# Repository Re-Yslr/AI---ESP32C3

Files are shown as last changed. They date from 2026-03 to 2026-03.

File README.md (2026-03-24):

# 机械AI仿生花 - Mechanical AI Bionic Flower

> 基于 xiaozhi-esp32 框架的毕业设计项目 | Graduation Design Project

## 项目简介

这是一个具有AI语音交互能力的机械仿生花项目。花朵可以根据AI对话状态自动开合，配合LED灯光效果，创造出富有生命力的交互体验。

**核心功能**：
- AI语音对话交互
- 花朵自动开合动画
- WS2812 RGB灯带氛围效果
- 3个物理按钮交互
- MCP协议智能设备控制

---

## 实物展示

### 功能演示

https://github.com/user-attachments/assets/功能演示.mp4

### 成品图片

| 框架成品 | 内部结构 |
|:---:|:---:|
| 框架成品图 | 内部成品 |

---

## 制作想法

### 设计理念

本项目试图探索"人机交互"的新形式——让AI不只是冰冷的屏幕对话，而是赋予它一个可以触摸、可以感知的物理实体。

**灵感来源**：
- 花朵的开合如同呼吸，具有自然的生命韵律
- AI"苏醒"时花朵绽放，"休眠"时花朵合拢
- 语音对话时花朵轻轻摇摆，仿佛在倾听和思考

### 工作流程

```
┌─────────────────────────────────────────────────────────┐
│                      状态流转                            │
├─────────────────────────────────────────────────────────┤
│                                                         │
│   [待命] ──唤醒词──> [聆听] ──识别完成──> [思考]        │
│     │                  │                  │             │
│   花朵合拢          花朵绽放            花朵摇摆         │
│   灯光常亮          灯光呼吸            灯光闪烁         │
│     │                  │                  │             │
│     └────────────────<┴────<──对话结束──<┘             │
│                                                         │
└─────────────────────────────────────────────────────────┘
```

## 目录结构

```
AI---ESP32C3/
│
├── main/
│   ├── boards/
│   │   ├── mechanical-flower/     # ← 本项目核心代码
│   │   │   ├── config.h           # 引脚配置
│   │   │   ├── config.json        # 板卡配置
│   │   │   ├── mechanical_flower_board.cc      # 板卡初始化
│   │   │   ├── mechanical_flower_controller.*  # 花朵控制器
│   │   │   ├── mechanical_flower_audio_codec.* # 音频编解码
│   │   │   ├── servo_controller.*              # 舵机控制
│   │   │   ├── flower_led_controller.*         # LED控制
│   │   │   └── flower_led.h       # LED驱动
│   │   │
│   │   └── common/                # 公共板卡依赖
│   │
│   ├── audio/                     # 音频处理模块
│   ├── display/                   # 显示模块
│   ├── led/                       # LED基础驱动
│   └── protocols/                 # 通信协议
│
├── stl/                           # ← 3D打印模型文件
│   ├── 花瓣.stl                   # 花瓣部件
│   ├── 树叶.stl                   # 叶子部件
│   ├── 花茎与花盆盖.stl           # 花茎和花盆盖
│   ├── 花盆内部.stl               # 花盆内部结构
│   ├── 齿轮.stl                   # 齿轮传动
│   ├── 齿条.stl                   # 齿条传动
│   ├── 连杆1.stl                  # 连杆组件1
│   └── 连杆2.stl                  # 连杆组件2
│
├── docs/                          # 项目文档
├── LICENSE                        # MIT协议 + 贡献者声明
└── CMakeLists.txt                 # 构建配置
```

---

## 代码路径说明

### 核心控制文件

| 文件 | 功能 |
|---|---|
| `main/boards/mechanical-flower/config.h` | GPIO引脚配置、舵机角度参数 |
| `main/boards/mechanical-flower/mechanical_flower_controller.cc` | 花朵动作控制核心逻辑 |
| `main/boards/mechanical-flower/servo_controller.cc` | SG90舵机PWM驱动 |
| `main/boards/mechanical-flower/flower_led_controller.cc` | WS2812灯带控制 |

### 关键功能

**1. 花朵动作控制** (`mechanical_flower_controller.cc`)
- `OpenFlower()` - 花朵绽放
- `CloseFlower()` - 花朵合拢
- `Wiggle()` - 花朵摇摆动画
- `WaterFlower()` - 浇水动作

**2. 舵机控制** (`servo_controller.cc`)
- 50Hz PWM信号生成
- 角度范围：0° ~ 48°
- 平滑移动动画

**3. LED控制** (`flower_led_controller.cc`)
- 颜色设置
- 呼吸效果
- 预设颜色方案

---

## 3D模型说明

### 模型文件位置
```
stl/
├── 花瓣.stl          # 3D打印 - 花瓣主体
├── 树叶.stl          # 3D打印 - 装饰叶子
├── 花茎与花盆盖.stl  # 3D打印 - 支撑结构
├── 花盆内部.stl      # 3D打印 - 电子元件安装座
├── 齿轮.stl         # 传动机构
├── 齿条.stl         # 传动机构
├── 连杆1.stl        # 花瓣驱动连杆
└── 连杆2.stl        # 花瓣驱动连杆
```

舵机通过齿轮齿条机构驱动连杆，连杆带动花瓣实现开合运动。

---

## 硬件连接

### 引脚分配表 (ESP32-C3)

| 模块 | ESP32引脚 | 模块引脚 | 说明 |
|---|---|---|---|
| **INMP441麦克风** | | | |
| | GPIO3 | BCLK/SCK | I2S位时钟 |
| | GPIO2 | LRCLK/WS | I2S左右声道时钟 |
| | GPIO10 | DIN/SD | I2S数据输入 |
| **MAX98357A功放** | | | |
| | GPIO3 | BCLK | I2S位时钟（共用） |
| | GPIO2 | LRC | I2S时钟（共用） |
| | GPIO13 | DIN | I2S数据输出 |
| **SG90舵机** | GPIO9 | 信号线 | PWM控制 (50Hz) |
| **WS2812灯带** | GPIO19 | DIN | 数据输入 |
| **按钮1** | GPIO0 | - | WiFi配网/蓝牙 |
| **按钮2** | GPIO1 | - | 打断对话 |
| **按钮3** | GPIO12 | - | 浇水功能 |

### 电源要求

- ESP32-C3: 3.3V
- INMP441: 3.3V（不可接5V）
- MAX98357A: 5V
- SG90舵机: 5V
- WS2812: 5V

---

## 编译与烧录

### 环境要求

- ESP-IDF v5.4+
- Python 3.8+
- Git

### 编译步骤

```bash
# 克隆仓库
git clone https://github.com/Re-Yslr/AI---ESP32C3.git
cd AI---ESP32C3

# 设置目标芯片
idf.py set-target esp32c3

# 编译
idf.py build

# 烧录
idf.py -p COM端口 flash monitor
```

### 配网

首次启动后，点击按钮1进入WiFi配网模式，或长按开启蓝牙配网。

---

## 技术栈

- **硬件**: ESP32-C3, INMP441, MAX98357A, SG90, WS2812
- **框架**: xiaozhi-esp32 (MIT License)
- **协议**: MCP (Model Context Protocol)
- **音频**: I2S全双工, OPUS编解码
- **AI后端**: 通义千问 / DeepSeek

---

## 致谢

本项目基于 [xiaozhi-esp32](https://github.com/78/xiaozhi-esp32) 开源框架开发。

- **Original Framework**: Shenzhen Xinzhi Future Technology Co., Ltd.
- **Project Contributor**: [Re-Yslr](https://github.com/Re-Yslr)

---

## License

MIT License - 详见 [LICENSE](LICENSE) 文件

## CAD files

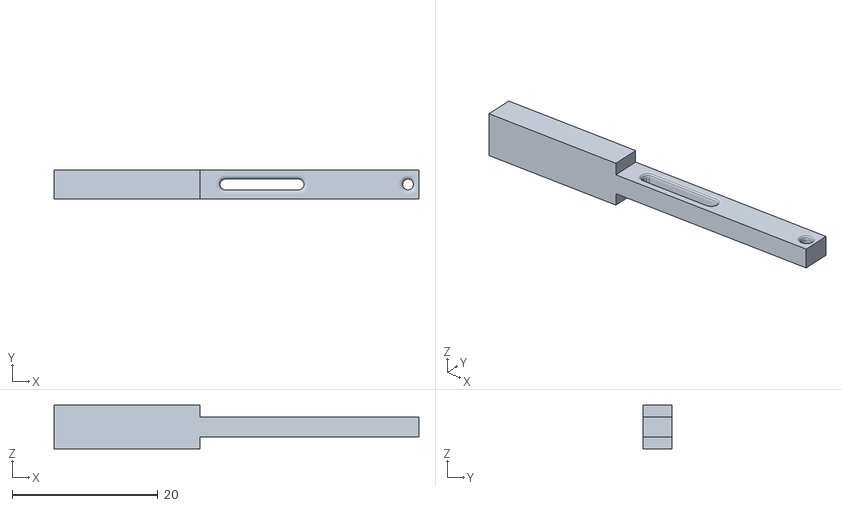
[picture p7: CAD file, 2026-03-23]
stl/连杆2.stl
50.0 x 4.00 x 6.00

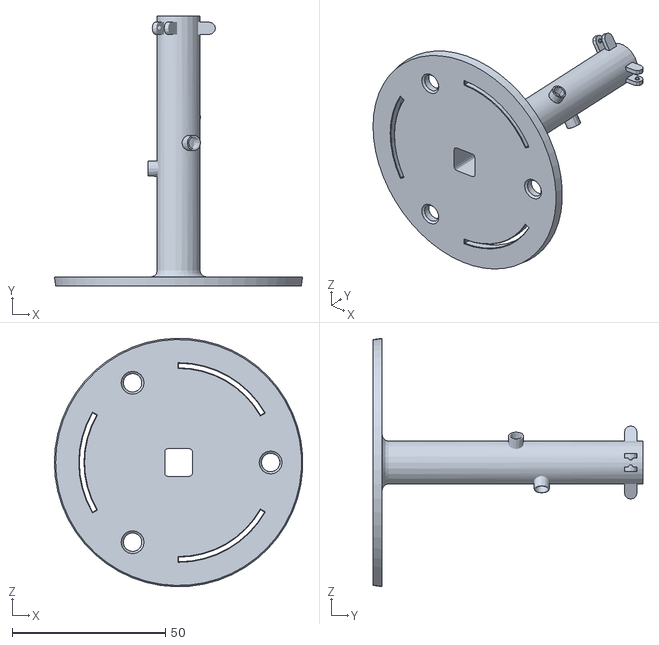
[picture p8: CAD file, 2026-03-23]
stl/花茎与花盆盖.stl
80.9 x 88.0 x 81.0

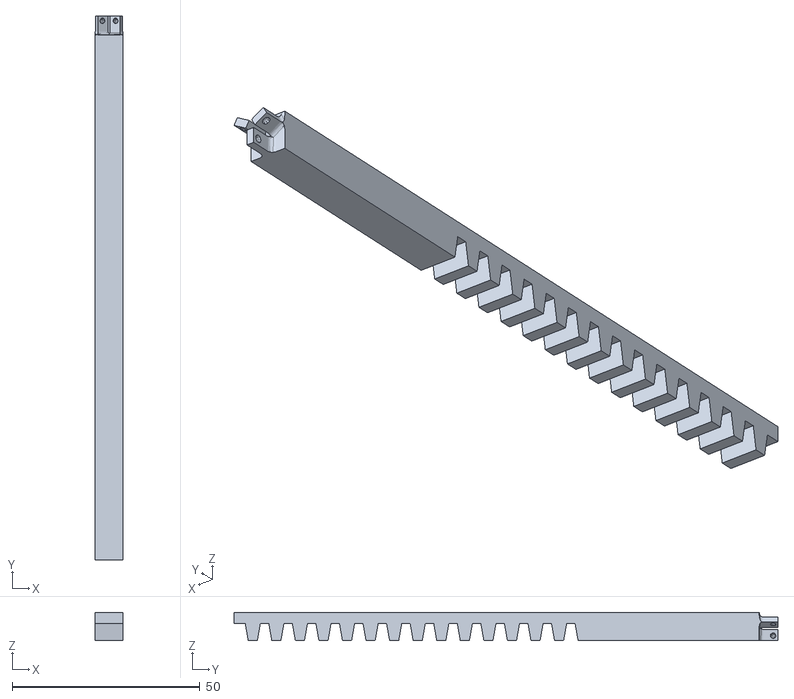
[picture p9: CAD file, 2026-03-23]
stl/齿条.stl
7.50 x 145.0 x 7.50

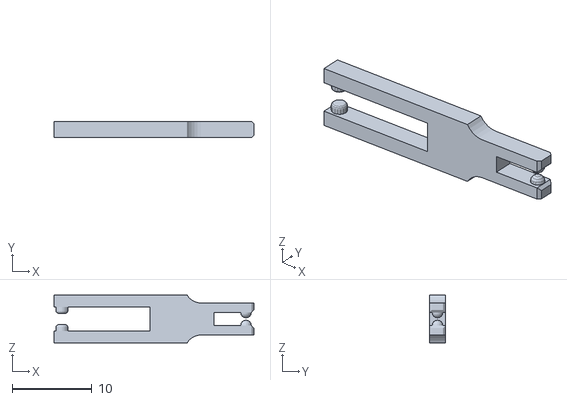
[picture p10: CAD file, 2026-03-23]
stl/连杆1.stl
25.0 x 2.00 x 6.00

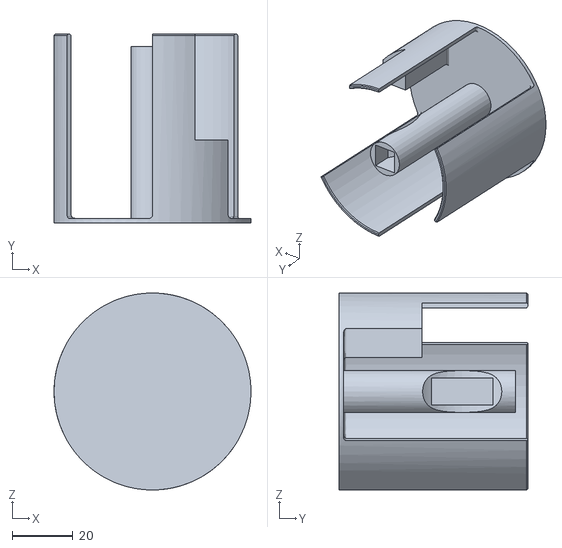
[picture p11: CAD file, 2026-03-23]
stl/花盆内部.stl
64.7 x 62.0 x 64.7

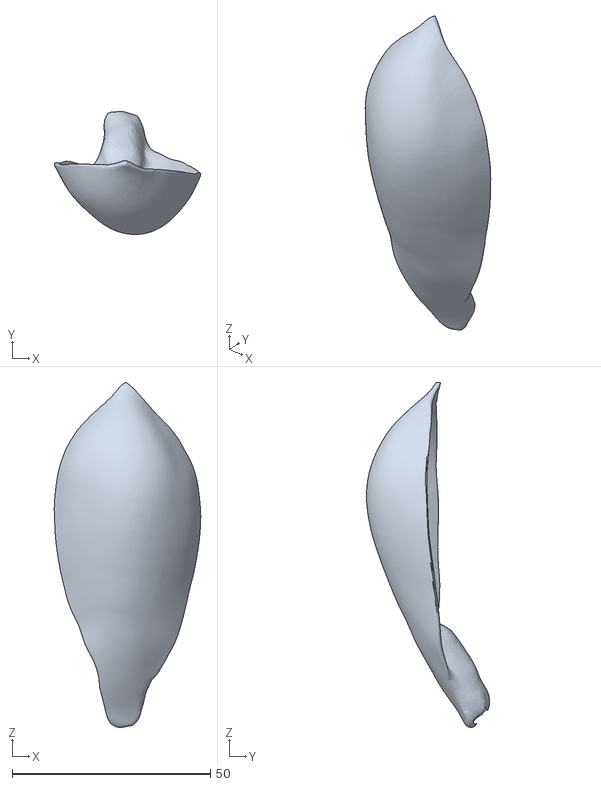
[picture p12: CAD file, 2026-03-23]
stl/花瓣.stl
37.0 x 31.1 x 87.1

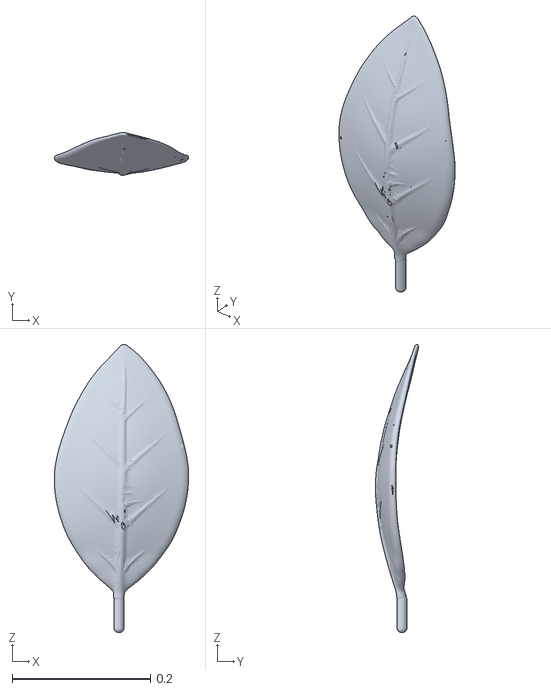
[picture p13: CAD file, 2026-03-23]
stl/树叶.stl
0.194 x 0.0624 x 0.416

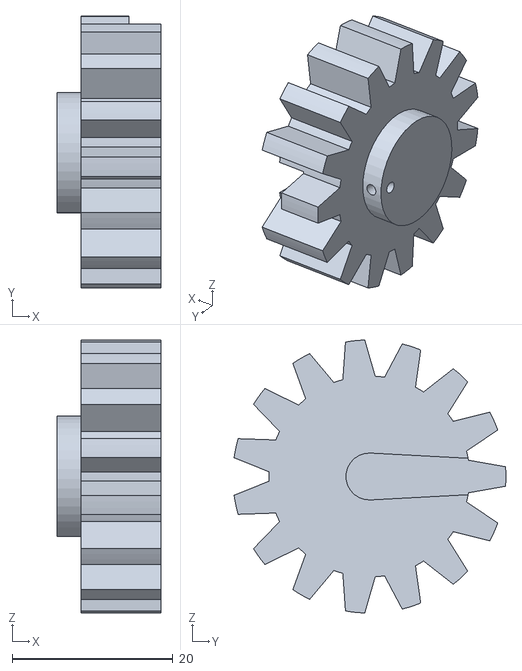
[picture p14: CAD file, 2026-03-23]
stl/齿轮.stl
13.0 x 33.8 x 34.0

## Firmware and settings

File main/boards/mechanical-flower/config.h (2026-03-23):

/**
 * @file config.h
 * @brief 机械AI仿生花引脚配置文件
 * 
 * 本文件定义了机械AI仿生花项目的所有GPIO引脚配置
 * 硬件平台：ESP32-C3
 * 
 * 【引脚分配表】
 * ┌─────────────┬──────────┬──────────┬────────────────────────────┐
 * │ 模块        │ ESP32引脚 │ 模块引脚  │ 说明                       │
 * ├─────────────┼──────────┼──────────┼────────────────────────────┤
 * │ INMP441麦克风│ GPIO3    │ BCLK/SCK │ I2S位时钟                  │
 * │ INMP441麦克风│ GPIO2    │ LRCLK/WS │ I2S左右声道时钟            │
 * │ INMP441麦克风│ GPIO10   │ DIN/SD   │ I2S数据输入                │
 * │ INMP441麦克风│ 3.3V     │ VDD      │ 电源正极                   │
 * │ INMP441麦克风│ GND      │ GND      │ 地线                       │
 * │ INMP441麦克风│ GND      │ L/R      │ 左右声道选择（接地=左声道）│
 * ├─────────────┼──────────┼──────────┼────────────────────────────┤
 * │ MAX98357A功放│ GPIO3    │ BCLK     │ I2S位时钟（与麦克风共用）  │
 * │ MAX98357A功放│ GPIO2    │ LRC      │ I2S左右声道时钟（共用）    │
 * │ MAX98357A功放│ GPIO13   │ DIN      │ I2S数据输出                │
 * │ MAX98357A功放│ 5V       │ VIN      │ 电源正极                   │
 * │ MAX98357A功放│ GND      │ GND      │ 地线                       │
 * ├─────────────┼──────────┼──────────┼────────────────────────────┤
 * │ SG90舵机    │ GPIO9    │ 信号线    │ PWM控制 (50Hz)             │
 * │ SG90舵机    │ 5V       │ VCC      │ 电源正极                   │
 * │ SG90舵机    │ GND      │ GND      │ 地线                       │
 * ├─────────────┼──────────┼──────────┼────────────────────────────┤
 * │ WS2812灯带  │ GPIO19   │ DIN      │ 数据输入                   │
 * │ WS2812灯带  │ 5V       │ VCC      │ 电源正极                   │
 * │ WS2812灯带  │ GND      │ GND      │ 地线                       │
 * ├─────────────┼──────────┼──────────┼────────────────────────────┤
 * │ 按钮1       │ GPIO0    │ 引脚1    │ 单击联网，长按开启蓝牙     │
 * │ 按钮1       │ GND      │ 引脚2    │ 地线                       │
 * │ 按钮2       │ GPIO1    │ 引脚1    │ 单击打断对话               │
 * │ 按钮2       │ GND      │ 引脚2    │ 地线                       │
 * │ 按钮3       │ GPIO12   │ 引脚1    │ 单击浇水，长按查询浇水时间 │
 * │ 按钮3       │ GND      │ 引脚2    │ 地线                       │
 * └─────────────┴──────────┴──────────┴────────────────────────────┘
 * 
 * @note 所有模块的GND必须连接在一起（共地）
 * @note INMP441必须接3.3V，不可接5V
 * @note GPIO引脚输出电压为3.3V，输入耐压也为3.3V
 */

#ifndef _BOARD_CONFIG_H_
#define _BOARD_CONFIG_H_

#include <driver/gpio.h>

/* ============================================================================
 * 音频配置
 * ============================================================================ */

/**
 * @brief 音频采样率
 * ESP32-C3全双工模式下TX和RX必须使用相同采样率
 * 使用16kHz统一采样率
 */
#define AUDIO_INPUT_SAMPLE_RATE  16000
#define AUDIO_OUTPUT_SAMPLE_RATE 16000

/* ============================================================================
 * INMP441 I2S麦克风引脚配置
 * ============================================================================ */

/**
 * @brief I2S位时钟引脚 (BCLK/SCK)
 * 连接INMP441的SCK引脚，与MAX98357A共用
 */
#define AUDIO_I2S_MIC_GPIO_SCK   GPIO_NUM_3

/**
 * @brief I2S左右声道时钟引脚 (LRCLK/WS)
 * 连接INMP441的WS引脚，与MAX98357A共用
 */
#define AUDIO_I2S_MIC_GPIO_WS    GPIO_NUM_2

/**
 * @brief I2S数据输入引脚 (DIN/SD)
 * 连接INMP441的SD引脚
 */
#define AUDIO_I2S_MIC_GPIO_DIN   GPIO_NUM_10

/* ============================================================================
 * MAX98357A I2S功放引脚配置
 * 
 * MAX98357A是I2S数字输入功放，与麦克风共用BCLK和WS引脚
 * 接线：
 *   MAX98357A BCLK → GPIO3（与麦克风共用）
 *   MAX98357A LRC  → GPIO2（与麦克风共用）
 *   MAX98357A DIN  → GPIO13
 *   MAX98357A VIN  → 5V
 *   MAX98357A GND  → GND
 * ============================================================================ */

/**
 * @brief MAX98357A功放数据输出引脚
 */
#define AUDIO_I2S_AMP_GPIO_DOUT  GPIO_NUM_13

/* ============================================================================
 * SG90舵机配置
 * ============================================================================ */

/**
 * @brief SG90舵机PWM控制引脚
 * 
 * PWM参数：
 * - 频率：50Hz (周期20ms)
 * - 脉宽范围：500μs ~ 2500μs 对应 0° ~ 180°
 * 
 * 注意：GPIO9在ESP32-C3上连接内部Flash，但仍可用于PWM输出
 */
#define SERVO_GPIO               GPIO_NUM_9

/* ============================================================================
 * WS2812灯带配置
 * ============================================================================ */

/**
 * @brief WS2812 RGB灯带数据输入引脚
 * 
 * WS2812时序要求严格，通常使用SPI+DMA方式驱动
 * 颜色格式：GRB (绿-红-蓝)
 */
#define WS2812_GPIO              GPIO_NUM_19

/* ============================================================================
 * 按钮配置
 * ============================================================================ */

/**
 * @brief 按钮1引脚 - 联网/蓝牙
 * GPIO0（开发板上的BOOT按钮）
 * - 单击：进入WiFi配网模式
 * - 长按：开启蓝牙配网
 */
#define BUTTON1_GPIO             GPIO_NUM_0

/**
 * @brief 按钮2引脚 - 打断对话
 * GPIO1
 * - 单击：打断当前对话，花朵合拢
 */
#define BUTTON2_GPIO             GPIO_NUM_1

/**
 * @brief 按钮3引脚 - 互动功能
 * GPIO12（输入专用引脚，但按钮为输入，可正常使用）
 * - 单击：浇水功能
 * - 长按：查询上次浇水时间
 */
#define BUTTON3_GPIO             GPIO_NUM_12
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

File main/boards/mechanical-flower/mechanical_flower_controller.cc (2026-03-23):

/**
 * @file mechanical_flower_controller.cc
 * @brief 机械AI仿生花控制器实现
 * 
 * 舵机控制逻辑：
 * - 合拢位置：0°（花瓣收起）
 * - 开花位置：48°（顺时针旋转，花瓣展开）
 * - 摇摆：以48°为中心，向逆时针方向（角度减小）平滑摆动
 * - 开机默认：合拢状态（0°，用户手动调节机械结构）
 */

#include "mechanical_flower_controller.h"
#include "application.h"
#include "device_state_machine.h"
#include "config.h"
#include <esp_log.h>
#include <freertos/FreeRTOS.h>
#include <freertos/task.h>
#include <ctime>

#define TAG "FlowerController"

MechanicalFlowerController& MechanicalFlowerController::GetInstance() {
    static MechanicalFlowerController instance;
    return instance;
}

MechanicalFlowerController::MechanicalFlowerController()
    : servo_(nullptr), 
      open_angle_(SERVO_OPEN_ANGLE),      // 48°（开花位置）
      close_angle_(SERVO_CLOSE_ANGLE),    // 0°（合拢位置）
      initialized_(false), 
      state_listener_id_(-1), 
      wiggling_(false), 
      wiggle_thread_(nullptr),
      action_in_progress_(false),
      battery_capacity_mah_(2000),        // 默认电池容量 2000mAh
      battery_remaining_mah_(2000.0f),    // 初始满电
      last_state_change_time_(0),
      current_tracked_state_(kDeviceStateUnknown),
      last_charge_time_(0) {
}

MechanicalFlowerController::~MechanicalFlowerController() {
    StopWiggling();
    
    // 慢速合拢花朵（重启时的优雅关闭）
    if (initialized_ && servo_) {
        ESP_LOGI(TAG, "Graceful shutdown: closing flower slowly");
        servo_->MoveTo(close_angle_, 2000);  // 慢速合拢，与正常合拢速度一致
    }
    
    // 移除状态监听器
    if (state_listener_id_ >= 0) {
        auto& state_machine = Application::GetInstance().GetDeviceStateMachine();
        state_machine.RemoveStateChangeListener(state_listener_id_);
        state_listener_id_ = -1;
    }
}

void MechanicalFlowerController::Initialize(int servo_gpio) {
    if (initialized_) return;
    
    // 从设置中读取角度配置（可被用户覆盖）
    Settings settings("flower", false);
    open_angle_ = settings.GetInt("open_angle", SERVO_OPEN_ANGLE);    // 默认48°（开花位置）
    close_angle_ = settings.GetInt("close_angle", SERVO_CLOSE_ANGLE); // 默认0°（合拢位置）
    
    // 读取上次保存的舵机角度（用于重启时恢复位置）
    int saved_angle = settings.GetInt("current_angle", close_angle_);  // 默认为合拢位置
    
    // 读取电量追踪配置
    // 电量以 mAh 为单位，存储时乘以 100 以提高精度（避免使用 float）
    battery_capacity_mah_ = settings.GetInt("battery_capacity_mah", 2000);
    int remaining_mah_x100 = settings.GetInt("battery_remaining_mah_x100", battery_capacity_mah_ * 100);
    battery_remaining_mah_ = remaining_mah_x100 / 100.0f;
    last_charge_time_ = (time_t)settings.GetInt("last_charge_time", 0);
    
    // 初始化状态追踪
    last_state_change_time_ = time(nullptr);
    current_tracked_state_ = kDeviceStateStarting;
    
    // 创建舵机控制器（初始化时不输出PWM）
    servo_ = std::make_unique<ServoController>(servo_gpio);
    
    // 设置舵机的内部状态为保存的角度（不移动）
    servo_->SetAngleWithoutOutput(saved_angle);
    ESP_LOGI(TAG, "Servo restored to saved angle: %d°", saved_angle);
    
    // 如果保存的角度不是合拢位置，慢速移动到合拢位置
    if (saved_angle != close_angle_) {
        ESP_LOGI(TAG, "Moving to close position slowly...");
        servo_->MoveTo(close_angle_, 2000);  // 慢速合拢，2秒
    }
    
    // 注册状态变化监听器
    auto& state_machine = Application::GetInstance().GetDeviceStateMachine();
    state_listener_id_ = state_machine.AddStateChangeListener(
        [this](DeviceState old_state, DeviceState new_state) {
            OnStateChanged(old_state, new_state);
        });
    
    // 注册MCP工具
    RegisterMcpTools();
    
    initialized_ = true;
    ESP_LOGI(TAG, "Flower controller initialized, open=%d° (顺时针), close=%d° (逆时针)", 
             open_angle_, close_angle_);
    ESP_LOGI(TAG, "Battery: %d mAh capacity, %.1f mAh remaining (%.0f%%)", 
             battery_capacity_mah_, battery_remaining_mah_, 
             battery_remaining_mah_ / battery_capacity_mah_ * 100.0f);
}

void MechanicalFlowerController::OnStateChanged(DeviceState old_state, DeviceState new_state) {
    ESP_LOGI(TAG, "State changed: %d -> %d", (int)old_state, (int)new_state);
    
    // 更新电量消耗和追踪状态（合并到一个锁作用域内，避免死锁）
    {
        std::lock_guard<std::mutex> lock(battery_mutex_);
        
        // 计算旧状态的电量消耗
        if (old_state != kDeviceStateUnknown) {
            time_t now = time(nullptr);
            long duration_seconds = now - last_state_change_time_;
            
            if (duration_seconds > 0) {
                int current_ma = GetStatePowerConsumption(old_state);
                float consumed_mah = (float)(current_ma * duration_seconds) / 3600.0f;
                battery_remaining_mah_ -= consumed_mah;
                if (battery_remaining_mah_ < 0) battery_remaining_mah_ = 0;
                
                ESP_LOGD(TAG, "Battery: %.2f mAh consumed in %ld sec", consumed_mah, duration_seconds);
            }
        }
        
        // 更新追踪状态和时间
        current_tracked_state_ = new_state;
        last_state_change_time_ = time(nullptr);
    }
    
    // 处理舵机操作
    servo_mutex_.lock();
    
    switch (new_state) {
        case kDeviceStateIdle:
            // 待命状态：合拢花朵，停止摇摆
            StopWigglingInternal();
            servo_mutex_.unlock();
            JoinWiggleThread();
            servo_mutex_.lock();
            CloseFlowerInternal();
            break;
            
        case kDeviceStateListening:
            // 仅在聆听状态时开花（不包括连接状态）
            StopWigglingInternal();
            servo_mutex_.unlock();
            JoinWiggleThread();
            servo_mutex_.lock();
            OpenFlowerInternal();
            break;
            
        case kDeviceStateSpeaking:
            // AI说话状态：开始平滑摇摆
            StartWigglingInternal();
            break;
            
        case kDeviceStateConnecting:
            // 连接状态：不做任何动作，保持当前状态
            break;
            
        default:
            StopWigglingInternal();
            servo_mutex_.unlock();
            JoinWiggleThread();
            servo_mutex_.lock();
            break;
    }
    
    servo_mutex_.unlock();
}

void MechanicalFlowerController::OpenFlower() {
    if (!initialized_ || !servo_) return;
    
    std::lock_guard<std::mutex> lock(servo_mutex_);
    OpenFlowerInternal();
}

void MechanicalFlowerController::OpenFlowerInternal() {
    if (!initialized_ || !servo_) return;
    
    ESP_LOGI(TAG, "Opening flower (clockwise to %d°)...", open_angle_);
    servo_->MoveTo(open_angle_, 2000);  // 顺时针旋转到开花位置（48°），慢速移动
    
    // 保存当前角度到Settings（用于重启时恢复位置）
    Settings settings("flower", true);
    settings.SetInt("current_angle", open_angle_);
}

void MechanicalFlowerController::CloseFlower() {
    if (!initialized_ || !servo_) return;
    
    std::lock_guard<std::mutex> lock(servo_mutex_);
    CloseFlowerInternal();
}
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

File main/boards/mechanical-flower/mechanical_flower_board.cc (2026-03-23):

/**
 * @file mechanical_flower_board.cc
 * @brief 机械AI仿生花开发板驱动 - 完整版本
 * 
 * 【硬件配置】
 * - 主控芯片：ESP32-C3
 * - 语音采集：INMP441 I2S MEMS麦克风
 * - 音频输出：MAX98357A I2S数字功放
 * - 运动控制：SG90舵机（GPIO9）
 * - 灯光效果：WS2812 RGB灯带（GPIO19）
 * - 按钮1（GPIO0）：单击重启，长按配网
 * - 按钮2（GPIO1）：单击打断对话
 * - 按钮3（GPIO12）：单击浇水，长按查询上次浇水时间
 * 
 * 【交互模式】
 * - 默认：唤醒词"小花小花"触发对话
 * - 按钮交互：三个按钮提供快捷功能
 * 
 * 【LED效果】
 * - 聆听状态：呼吸灯效果
 * - 待命状态：常亮
 */

#include "wifi_board.h"
#include "display/display.h"
#include "mechanical_flower_audio_codec.h"
#include "mechanical_flower_controller.h"
#include "flower_led_controller.h"
#include "application.h"
#include "button.h"
#include "config.h"
#include "press_to_talk_mcp_tool.h"
#include "mcp_server.h"
#include "protocol.h"
#include "settings.h"
#include "assets/lang_config.h"

#ifdef CONFIG_USE_ESP_BLUFI_WIFI_PROVISIONING
#include "blufi.h"
#endif

#include <esp_log.h>
#include <esp_system.h>
#include <driver/gpio.h>
#include <freertos/FreeRTOS.h>
#include <freertos/task.h>
#include <ctime>

#define TAG "MechanicalFlower"

// LED灯带数量
#define LED_STRIP_COUNT  3

// 长按时间阈值（毫秒）
#define LONG_PRESS_TIME_MS  1000

class MechanicalFlowerBoard : public WifiBoard {
private:
    Button button1_;  // GPIO0：联网/重启
    Button button2_;  // GPIO1：打断对话
    Button button3_;  // GPIO12：浇水/查询浇水时间
    PressToTalkMcpTool* press_to_talk_tool_ = nullptr;
    bool button1_long_press_triggered_ = false;  // 防止长按后触发单击

    void InitializeButtons() {
        // ========== 按钮1 (GPIO0)：单击重启，长按配网 ==========
        button1_.OnClick([this]() {
            // 如果长按已触发，忽略单击
            if (button1_long_press_triggered_) {
                button1_long_press_triggered_ = false;
                return;
            }
            
            ESP_LOGI(TAG, "Button1 clicked, restarting device...");
            esp_restart();
        });
        
        button1_.OnLongPress([this]() {
            // 设置长按标志，阻止后续单击
            button1_long_press_triggered_ = true;
            
            auto& app = Application::GetInstance();
            auto state = app.GetDeviceState();
            
            ESP_LOGI(TAG, "Button1 long pressed (WiFi config), state=%d", (int)state);
            
            // 在启动状态、待命状态或WiFi配置状态下，长按进入WiFi热点配网
            if (state == kDeviceStateStarting || state == kDeviceStateIdle || state == kDeviceStateWifiConfiguring) {
                EnterWifiConfigMode();
                return;
            }
            
            ESP_LOGI(TAG, "Button1 long pressed in state %d, ignored", (int)state);
        });
        
        // 长按说话模式：按下开始监听，松开停止
        button1_.OnPressDown([this]() {
            if (press_to_talk_tool_ && press_to_talk_tool_->IsPressToTalkEnabled()) {
                ESP_LOGI(TAG, "Button1 pressed, start listening...");
                Application::GetInstance().StartListening();
                
                // 开花表示正在说话
                MechanicalFlowerController::GetInstance().OpenFlower();
            }
        });
        
        button1_.OnPressUp([this]() {
            if (press_to_talk_tool_ && press_to_talk_tool_->IsPressToTalkEnabled()) {
                ESP_LOGI(TAG, "Button1 released, stop listening...");
                Application::GetInstance().StopListening();
            }
        });
        
        // ========== 按钮2 (GPIO1)：单击打断对话 ==========
        button2_.OnClick([this]() {
            auto& app = Application::GetInstance();
            auto state = app.GetDeviceState();
            
            ESP_LOGI(TAG, "Button2 clicked (interrupt), state=%d", (int)state);
            
            // 如果正在说话或聆听，打断对话
            if (state == kDeviceStateSpeaking || state == kDeviceStateListening) {
                // 打断AI说话
                app.AbortSpeaking(AbortReason::kAbortReasonNone);
                
                // 设置取消标志，让TTS结束后进入待命
                app.SetCancelAfterSpeaking(true);
                
                // 立即合拢花朵
                MechanicalFlowerController::GetInstance().StopWiggling();
                MechanicalFlowerController::GetInstance().CloseFlower();
                
                // 如果在聆听状态，停止聆听
                if (state == kDeviceStateListening) {
                    app.StopListening();
                }
                
                ESP_LOGI(TAG, "Conversation interrupted, flower closed");
            }
        });
        
        // ========== 按钮3 (GPIO12)：暂时闲置 ==========
        // 未来可扩展功能
        button3_.OnClick([this]() {
            ESP_LOGI(TAG, "Button3 clicked (reserved)");
            // 暂时闲置，未来可扩展
        });
        
        button3_.OnLongPress([this]() {
            ESP_LOGI(TAG, "Button3 long pressed (reserved)");
            // 暂时闲置，未来可扩展
        });
        
        ESP_LOGI(TAG, "Buttons initialized:");
        ESP_LOGI(TAG, "  Button1 (GPIO%d): Click=Restart, LongPress=WiFi", BUTTON1_GPIO);
        ESP_LOGI(TAG, "  Button2 (GPIO%d): Click=Interrupt", BUTTON2_GPIO);
        ESP_LOGI(TAG, "  Button3 (GPIO%d): Reserved", BUTTON3_GPIO);
    }
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

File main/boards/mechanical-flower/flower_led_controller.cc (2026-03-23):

/**
 * @file flower_led_controller.cc
 * @brief 机械花LED灯带控制器实现
 */

#include "flower_led_controller.h"
#include "application.h"
#include "device_state.h"
#include <esp_log.h>
#include <random>

#define TAG "FlowerLed"

// 预设颜色表（支持中英文别名）
const FlowerLedColorPreset flower_led_color_presets[] = {
    // 红色系
    {"red",         255,  50,  50},   // 红色
    {"crimson",     220,  20,  60},   // 深红
    {"maroon",      128,   0,   0},   // 栗色
    {"coral",       255, 127,  80},   // 珊瑚色
    {"salmon",      250, 128, 114},   // 鲑鱼色
    
    // 橙色系
    {"orange",      255, 150,  50},   // 橙色
    {"darkorange",  255, 140,   0},   // 深橙
    
    // 黄色系
    {"yellow",      255, 255,  50},   // 黄色
    {"gold",        255, 215,   0},   // 金色
    {"khaki",       240, 230, 140},   // 卡其色
    
    // 绿色系
    {"green",        50, 255,  50},   // 绿色
    {"lime",        200, 255,   0},   // 青柠
    {"forest",       34, 139,  34},   // 森林绿
    {"olive",       128, 128,   0},   // 橄榄绿
    {"mint",        152, 255, 152},   // 薄荷绿
    
    // 青色系
    {"cyan",         50, 255, 255},   // 青色
    {"teal",          0, 128, 128},   // 蓝绿
    {"turquoise",    64, 224, 208},   // 绿松石
    
    // 蓝色系
    {"blue",         50,  50, 255},   // 蓝色
    {"navy",          0,   0, 128},   // 深蓝
    {"sky",         135, 206, 235},   // 天蓝
    {"royal",        65, 105, 225},   // 皇家蓝
    
    // 紫色系
    {"purple",      200,  50, 255},   // 紫色
    {"violet",      238, 130, 238},   // 紫罗兰
    {"magenta",     255,   0, 255},   // 洋红
    {"lavender",    230, 190, 255},   // 薰衣草
    
    // 粉色系
    {"pink",        255, 100, 150},   // 粉色
    {"rose",        255,   0, 127},   // 玫瑰粉
    {"peach",       255, 218, 185},   // 桃色
    
    // 白色系
    {"white",       255, 255, 255},   // 白色
    {"warm",        255, 200, 100},   // 暖白
    {"cool",        200, 200, 255},   // 冷白
    {"ivory",       255, 255, 240},   // 象牙白
};

const int flower_led_color_preset_count = sizeof(flower_led_color_presets) / sizeof(flower_led_color_presets[0]);

FlowerLedController& FlowerLedController::GetInstance() {
    static FlowerLedController instance;
    return instance;
}

FlowerLedController::FlowerLedController() {
    // 默认颜色：温暖粉色
    current_color_.red = 255;
    current_color_.green = 100;
    current_color_.blue = 150;
}

FlowerLedController::~FlowerLedController() {
    if (led_strip_) {
        delete led_strip_;
        led_strip_ = nullptr;
    }
}

void FlowerLedController::Initialize(gpio_num_t gpio, uint16_t led_count) {
    if (initialized_) {
        return;
    }
    
    ESP_LOGI(TAG, "初始化LED灯带: GPIO=%d, LED数量=%d", gpio, led_count);
    
    // 使用自定义的 FlowerLed 类
    led_strip_ = new FlowerLed(gpio, led_count);
    led_strip_->SetBrightness(32, 8);  // 默认亮度32，低亮度8
    
    // 恢复保存的颜色
    Settings settings("flower_led");
    int saved_r = settings.GetInt("red", current_color_.red);
    int saved_g = settings.GetInt("green", current_color_.green);
    int saved_b = settings.GetInt("blue", current_color_.blue);
    current_color_.red = static_cast<uint8_t>(saved_r);
    current_color_.green = static_cast<uint8_t>(saved_g);
    current_color_.blue = static_cast<uint8_t>(saved_b);
    led_strip_->SetBaseColor(current_color_);
    
    // 注册MCP工具
    RegisterMcpTools();
    
    initialized_ = true;
    ESP_LOGI(TAG, "LED灯带初始化完成");
}

void FlowerLedController::RegisterMcpTools() {
    auto& mcp_server = McpServer::GetInstance();
    
    // 设置颜色工具
    mcp_server.AddTool("self.flower_led.set_color",
        "设置机械花的LED灯带颜色。参数: red(0-255), green(0-255), blue(0-255)",
        PropertyList({
            Property("red", kPropertyTypeInteger, 255, 0, 255),
            Property("green", kPropertyTypeInteger, 100, 0, 255),
            Property("blue", kPropertyTypeInteger, 150, 0, 255)
        }),
        [this](const PropertyList& properties) -> ReturnValue {
            int red = properties["red"].value<int>();
            int green = properties["green"].value<int>();
            int blue = properties["blue"].value<int>();
            
            // 限制范围
            red = (red < 0) ? 0 : (red > 255 ? 255 : red);
            green = (green < 0) ? 0 : (green > 255 ? 255 : green);
            blue = (blue < 0) ? 0 : (blue > 255 ? 255 : blue);
            
            SetColor(red, green, blue);
            
            // 保存设置
            Settings settings("flower_led", true);
            settings.SetInt("red", red);
            settings.SetInt("green", green);
            settings.SetInt("blue", blue);
            
            char response[64];
            snprintf(response, sizeof(response), "已设置LED颜色为RGB(%d, %d, %d)", red, green, blue);
            return std::string(response);
        });
    
    // 更换颜色工具（随机或指定）
    mcp_server.AddTool("self.flower_led.change_color",
        "更换机械花的LED灯带颜色。当用户说'换个颜色'、'变个色'、'换颜色'、'变颜色'、'我不喜欢这个颜色'、'换个色'时调用。可以指定颜色名称或随机更换相近颜色。",
        PropertyList({
            Property("color", kPropertyTypeString, std::string(""))
        }),
        [this](const PropertyList& properties) -> ReturnValue {
            std::string color_name = properties["color"].value<std::string>();
            
            if (!color_name.empty()) {
                if (SetPresetColor(color_name)) {
                    return "已将LED颜色更改为" + color_name;
                } else {
                    // 颜色名称不识别，随机选择
                    ESP_LOGW(TAG, "未识别的颜色名称: %s，将随机选择相近颜色", color_name.c_str());
                }
            }
            
            // 计算与当前颜色相近的颜色（色相偏移）
            // 使用HSL色彩空间计算，选择色相相近的颜色
            int current_r = current_color_.red;
            int current_g = current_color_.green;
            int current_b = current_color_.blue;
            
            // 找出与当前颜色距离最小的几个颜色
            int best_indices[5] = {-1, -1, -1, -1, -1};
            int best_distances[5] = {999999, 999999, 999999, 999999, 999999};
            
            for (int i = 0; i < flower_led_color_preset_count; i++) {
                const auto& preset = flower_led_color_presets[i];
                int dr = preset.red - current_r;
                int dg = preset.green - current_g;
                int db = preset.blue - current_b;
                int distance = dr*dr + dg*dg + db*db;
                
                // 排除当前颜色（距离为0）
                if (distance < 100) continue;
                
                // 插入排序
                for (int j = 0; j < 5; j++) {
                    if (distance < best_distances[j]) {
                        for (int k = 4; k > j; k--) {
                            best_distances[k] = best_distances[k-1];
                            best_indices[k] = best_indices[k-1];
                        }
                        best_distances[j] = distance;
                        best_indices[j] = i;
                        break;
                    }
                }
            }
            
            // 从最相近的5个颜色中随机选一个
            int valid_count = 0;
            for (int i = 0; i < 5; i++) {
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

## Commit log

2026-03-23 feat: 添加机械花朵毕业设计项目
    - 基于 xiaozhi-esp32 框架 (MIT License)
    - 保留 mechanical-flower 板子项目 (ESP32-C3)
    - 添加 3D 打印 STL 模型文件 (8个)
    - 清理其他板子项目，只保留核心框架
    - 更新 LICENSE 添加贡献者声明
    [16m.csv, 16m_c3.csv, 16m_custom_wakeword.csv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]
2026-03-23 docs: 更新README，添加机械花朵项目说明
    - 添加项目简介和制作想法
    - 添加目录结构说明
    - 添加代码路径和模型路径说明
    - 添加硬件连接和编译指南
2026-03-23 docs: 添加实物展示栏
    - 添加功能演示视频
    - 添加框架成品图和内部成品图片
